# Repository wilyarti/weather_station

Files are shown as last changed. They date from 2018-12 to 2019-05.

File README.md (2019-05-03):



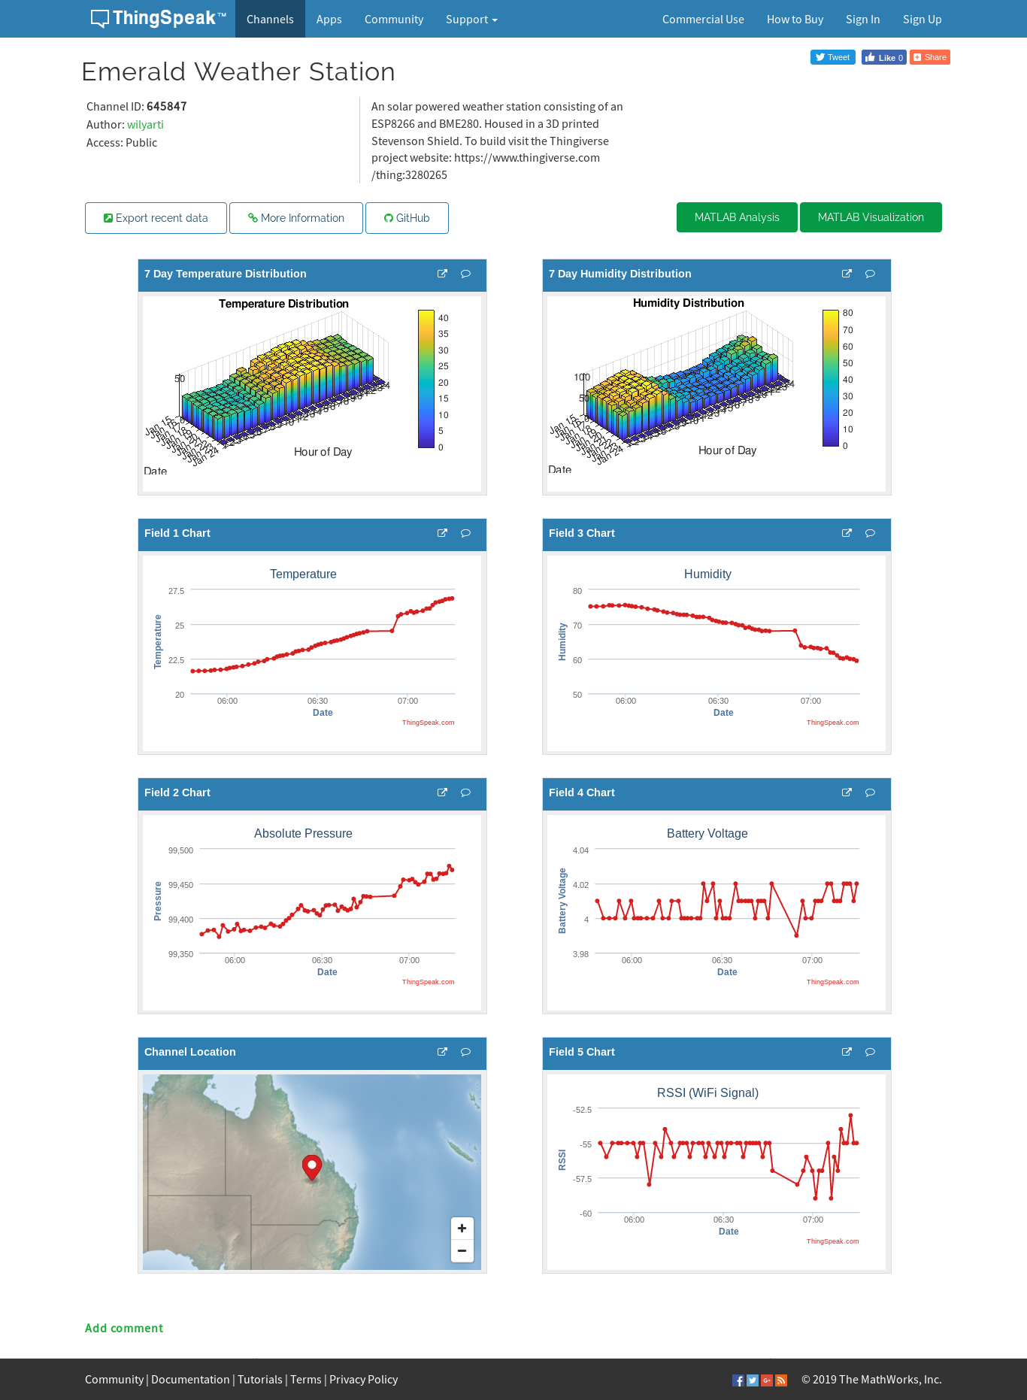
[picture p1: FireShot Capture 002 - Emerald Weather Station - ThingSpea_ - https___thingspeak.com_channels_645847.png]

# Introduction
This weather station has evolved over time. I originally undersized the roof and solar panels and created about 4 different versions. I started with a 0.1W solar panel (110mmx60mm) but it was under powered and only reached charge in the later afternoon.

My latest version uses a 165mm square solar panel and allows for the device to measure more frequently (every minute vs 5 minutes), I think it would be sufficient for low lit areas.

The latest firmware will create a WiFi access point that you can connect if the device is unable to connect to the internet via WiFi. This allows you to enter your ThingSpeak credentials, the sampling interval in seconds, and the WiFi access point credentials you would like to connect to. To access this page connect to the the ESP access point (named ESP... something) and navigate to http://192.168.4.1 and click on the relevent buttons.

After configuring the ESP's WiFi access point will disappear if it was configured correctly.

# Building
First select the roof based on the solar panel you are using and print all the parts. The parts are have all the holes necessary so all you need to do is screw it together.

# Configuring
Create a ThingSpeak account and a channel. Enter this channel number and your credentials into the ESP8266 configuration page that appears when you connect to the access point (as discussed above).

You can the code for a cool 3D bar graph in my GitHub repository, simple copy this and replace my ThingSpeak channel number with your own.

# Issues
Solar radiation is a big problem and will cause the inside of the structure to heat up. You will need to paint any surface that comes in contact with the sun with many layers of exterior UV resistant paint (I used high gloss and about 6 coats).

The latest design uses a large gap below the roof (which holds the solar panel) to allow for air flow. The roof is designed so that water will accumulate and drip off areas away from the electronics - although I am yet to prove it is sufficiently water resistant.

This version does not go to sleep, as it needs to listen for external interrupts to measure rain fall.

# Weather Issues and Web Interface
There were problems with previous version in wild weather where pressurized air would blow water into the internal Stevenson Screen damaging electronic components.

I have since devised a better design which seems to be more resistant to water ingress.

However it is not totally weather proof and strong winds and rain fall can still cause damages.

I have run out of ideas on how to solve this and any input is welcome.

You can use my web interface to view public ThingSpeak channels (see link below). It includes the following features:

1. Rain totals by 30 min, 1hr and 24 hr intervals
2. Live feed updates (1min)
3. Auto Absolute to Mean Sea Level Pressure conversion
4. Custom date ranges 
5. Custom interval ranges

# OTA Update
To configure Over The Air updates simple add this to your metadata field on your ThingSpeak channel:
~~~~
{
      "publishInterval" : 30,
      "firmwareVersion" : "11",
      "firmwareURL" : "link to firmware url"
}
~~~~
Don't forget to increment your firmware version in the source code as well (to prevent continuous upgrading to the same firmware):
~~~~
const String VERSION = "11";

~~~~

To generate the firmware "compilation" under "Show verbose output during: " in the Arduino settings dialog. Then copy the firmware listed in the compilation status window after clicking compile:
~~~~
<snip>
/home/undef/.arduino15/packages/esp8266/tools/xtensa-lx106-elf-gcc/1.20.0-26-gb404fb9-2/bin/xtensa-lx106-elf-size -A /tmp/arduino_build_27952/thingspeak_ota_weatherstation.ino.elf
Sketch uses 324156 bytes (31%) of program storage space. Maximum is 1044464 bytes.
Global variables use 32228 bytes (39%) of dynamic memory, leaving 49692 bytes for local variables. Maximum is 81920 bytes.

~~~~

In this case the firmware is located here: /tmp/arduino_build_27952/thingspeak_ota_weatherstation.ino.elf

# Parts list
- 18650 battery holder
- Diode for the solar panel
- Any ESP8266/ESP8285 module 
- TP4056 Battery Charger (or MCP73871 solar board)
- 6v Solar panel (165mmx165mm recommended)
- BME280 sensor
- SHT31 sensor
- UV VEML6075 Sensor
- Cabling
- Hot Glue
- Silicon Sealant (optional)
- Exterior UV resistant paint

[View source code.](https://github.com/wilyarti/weather_station "Source code.")
[View live data.](https://thingspeak.com/channels/645847 "View live data.")
[Use my API viewer.](https://opens3.net/weatherstats.html "Custom API Viewer")
[View Thingiverse entry](https://www.thingiverse.com/thing:3601839)

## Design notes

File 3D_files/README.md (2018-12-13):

### 3D files
These are the STL files, the project was created using AutoDesk Inventor. I will upload the ipt files at a later date.

The roof is foldable, in order to use it remove it from the build plate and allow to cool. Then place on the built plate and pre-heat the printer to 85c. When the part has heated fold and place up the right way and allow it to cool.

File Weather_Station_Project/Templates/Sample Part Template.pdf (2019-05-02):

THE INFORMATION AND/OR MATERIAL IN THIS DOCUMENT IS THE PROPERTY OF AND RESTRICTED INFORMATION AND/OR MATERIAL OF THE AUTHOR. THIS INFORMATION MAY NOT BE
USED, REPRODUCED, PUBLISHED OR DISCLOSED TO OTHERS WITHOUT WRITTEN AUTHORIZATION. IT IS TO BE USED ONLY FOR MANUFACTURING ITEMS SPECIFIED WITHIN THE DOCUMENT. {{{ 'v1.0' }}}

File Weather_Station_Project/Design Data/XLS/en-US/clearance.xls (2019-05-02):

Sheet: Ansi Unified Screw Threads
I | Sort Order -1
Fastener Type | Size | Shaft Diameters |  |  | Head Dimensions
 |  | Close | Normal | Loose | Diameter | Depth/Angle | Head Type
Flat Head Machine Screw (82) | #0 | 0.0635 | 0.07 | 0.073 | 0.119 | 82 | 2
Flat Head Machine Screw (82) | #1 | 0.076 | 0.081 | 0.089 | 0.146 | 82 | 2
Flat Head Machine Screw (82) | #2 | 0.089 | 0.096 | 0.1065 | 0.172 | 82 | 2
Flat Head Machine Screw (82) | #3 | 0.104 | 0.11 | 0.12 | 0.199 | 82 | 2
Flat Head Machine Screw (82) | #4 | 0.116 | 0.1285 | 0.136 | 0.225 | 82 | 2
Flat Head Machine Screw (82) | #5 | 0.1285 | 0.136 | 0.154 | 0.252 | 82 | 2
Flat Head Machine Screw (82) | #6 | 0.144 | 0.1495 | 0.1695 | 0.279 | 82 | 2
Flat Head Machine Screw (82) | #8 | 0.1695 | 0.177 | 0.1935 | 0.332 | 82 | 2
Flat Head Machine Screw (82) | #10 | 0.196 | 0.201 | 0.221 | 0.385 | 82 | 2
Flat Head Machine Screw (82) | #12 | 0.221 | 0.228 | 0.246 | 0.438 | 82 | 2
Flat Head Machine Screw (82) | 1/4 | 0.257 | 0.266 | 0.2812 | 0.507 | 82 | 2
Flat Head Machine Screw (82) | 5/16 | 0.323 | 0.332 | 0.3437 | 0.635 | 82 | 2
Flat Head Machine Screw (82) | 3/8 | 0.386 | 0.397 | 0.4062 | 0.762 | 82 | 2
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

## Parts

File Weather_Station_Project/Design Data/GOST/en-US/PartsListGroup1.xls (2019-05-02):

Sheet: Лист 1
Инв. № подл |  |  |  | Подп. и дата | Взам. инв. № | Инв. № дубл. |  |  | Подп. и дата
Формат | Зона | Поз. | Обозначение |  |  |  | Наименование |  |  |  |  |  | Кол. на исполнение
 |  |  |  |  |  |  |  |  |  |  |  | Лит.
 |  |  |  |  |  |  |  |  |  |  |  | Код
 |  |  |  |  |  |  |  | Изм. | Лист | № докум | Подпись |  | Дата
 |  |  |  |  |  |  |  | Разраб.
 |  |  |  |  |  |  |  | Пров.
 |  |  |  |  |  |  |  | Н.контр
 |  |  |  |  |  |  |  | Утв.
 |  |  |  |  |  |  |  |  |  |  |  |  |  | Копировал

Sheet: Лист 2
Инв. № подл |  |  |  | Подп. и дата | Взам. инв. № | Инв. № дубл. |  |  | Подп. и дата
Формат | Зона | Поз. | Обозначение |  |  |  | Наименование |  |  |  |  | Кол. на исполнение
 |  |  |  |  |  |  |  | Изм. | Лист | № докум. | Подп. | Дата
 |  |  |  |  |  |  |  |  |  |  |  |  | Копировал
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

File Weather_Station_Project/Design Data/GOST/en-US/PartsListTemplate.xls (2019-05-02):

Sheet: Лист 1
 | Формат | Зона |  | Поз. |  | Обозначение |  |  |  | Наименование |  |  |  | Кол. | Приме-чание
Подп. и дата
Инв. № дубл.
Взам. инв. №
Подп. и дата
 | Изм. |  | Лист |  | № докум |  | Подпись | Дата
Инв. № подл | Разраб. |  |  |  |  |  |  |  |  |  | Литера |  | Лист |  |  | Листов
 | Пров.
 | Н.контр
 | Утв.
 |  |  |  |  |  |  |  |  | Копировал |  |  | Формат А4

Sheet: Лист 2
 | Формат | Зона |  | Поз. |  | Обозначение |  |  |  | Наименование |  | Кол. | Приме-чание
Подп. и дата
Инв. № дубл.
Взам. инв. №
Подп. и дата
Инв. № подл
 | Изм. |  | Лист |  | № докум. |  | Подп. |  | Дата
 |  |  |  |  |  |  |  | Копировал |  |  | Формат А4
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

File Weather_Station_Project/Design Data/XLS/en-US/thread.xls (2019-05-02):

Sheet: Inch Tapping Threads
I Q X | Inch Tapping Threads |  | Sort Order - 5 |  | External |  |  |  |  |  |  | Internal
 |  |  |  |  |  | Major Dia |  | Pitch Dia |  | Minor Dia |  |  | Minor Dia |  | Pitch Dia |  | Major Dia |  | Tap Drill
Size | Size Suffix | Thread Designation | Custom Thread Designation | TPI | Class | Max | Min | Max | Min | Max | Min | Class | Min | Max | Min | Max | Min | Max | Basic
0.0600 |  | 0-48 | 0-48 | 48 | 2B | 0.0600 | 0.0540 | 0.0480 | 0.0435 | 0.0360 | 0.0330
0.0730 |  | 1-42 | 1-42 | 42 | 2B | 0.0750 | 0.0690 | 0.0620 | 0.0575 | 0.0490 | 0.0460
0.0860 |  | 2-32 | 2-32 | 32 | 2B | 0.0880 | 0.0820 | 0.0760 | 0.0710 | 0.0640 | 0.0600
0.0990 |  | 3-28 | 3-28 | 28 | 2B | 0.1010 | 0.0950 | 0.0880 | 0.0830 | 0.0750 | 0.0710
0.1120 |  | 4-24 | 4-24 | 24 | 2B | 0.1140 | 0.1080 | 0.1000 | 0.0950 | 0.0860 | 0.0820
0.1250 |  | 5-20 | 5-20 | 20 | 2B | 0.1300 | 0.1230 | 0.1120 | 0.1065 | 0.0940 | 0.0900
0.1380 |  | 6-20 | 6-20 | 20 | 2B | 0.1390 | 0.1320 | 0.1215 | 0.1155 | 0.1040 | 0.0990
0.1510 |  | 7-19 | 7-19 | 19 | 2B | 0.1540 | 0.1470 | 0.1345 | 0.1280 | 0.1150 | 0.1090
0.1640 |  | 8-18 | 8-18 | 18 | 2B | 0.1660 | 0.1590 | 0.1440 | 0.1375 | 0.1220 | 0.1160
0.1900 |  | 10-16 | 10-16 | 16 | 2B | 0.1890 | 0.1820 | 0.1650 | 0.1585 | 0.1410 | 0.1350
0.2160 |  | 12-14 | 12-14 | 14 | 2B | 0.2150 | 0.2080 | 0.1895 | 0.1825 | 0.1640 | 0.1570
0.2420 |  | 14-14 | 14-14 | 14 | 2B | 0.2410 | 0.2340 | 0.2130 | 0.2060 | 0.1850 | 0.1780
0.2500 |  | 1/4-14 | 1/4-14 | 14 | 2B | 0.2460 | 0.2370 | 0.2190 | 0.2110 | 0.1920 | 0.1850
0.3125 |  | 5/16-12 | 5/16-12 | 12 | 2B | 0.3150 | 0.3060 | 0.2795 | 0.2710 | 0.2440 | 0.2360
0.3750 |  | 3/8-12 | 3/8-12 | 12 | 2B | 0.3800 | 0.3710 | 0.3445 | 0.3350 | 0.3090 | 0.2990
0.4375 |  | 7/16-10 | 7/16-10 | 10 | 2B | 0.4400 | 0.4290 | 0.3995 | 0.3890 | 0.3590 | 0.3490
0.5000 |  | 1/2-10 | 1/2-10 | 10 | 2B | 0.5040 | 0.4930 | 0.4635 | 0.4530 | 0.4230 | 0.4130

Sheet: Metric Forming Screw Threads
M P X | Metric Forming Screw Threads |  | Sort Order - 6 |  | External |  |  |  |  |  |  | Internal
 |  |  |  |  |  | Major Dia |  | Pitch Dia |  | Minor Dia |  |  | Minor Dia |  | Pitch Dia |  | Major Dia |  | Tap Drill
Size | Size Suffix | Thread Designation | Custom Thread Designation | Pitch | Class | Max | Min | Max | Min | Max | Min | Class | Min | Max | Min | Max | Min | Max | Basic
1.5 |  | 1.5x0.5 | 1.5x0.5 | 0.5 | 6g | 1.520 | 1.380 | 1.215 | 1.110 | 0.910 | 0.840
1.5 |  | ST1.5x0.5 | ST1.5x0.5 | 0.5 | 6g | 1.520 | 1.380 | 1.215 | 1.110 | 0.910 | 0.840
1.9 |  | 1.9x0.6 | 1.9x0.6 | 0.6 | 6g | 1.900 | 1.760 | 1.570 | 1.465 | 1.240 | 1.170
1.9 |  | ST1.9x0.6 | ST1.9x0.6 | 0.6 | 6g | 1.900 | 1.760 | 1.570 | 1.465 | 1.240 | 1.170
2.2 |  | 2.2x0.8 | 2.2x0.8 | 0.8 | 6g | 2.240 | 2.100 | 1.935 | 1.810 | 1.630 | 1.520
2.2 |  | ST2.2x0.8 | ST2.2x0.8 | 0.8 | 6g | 2.240 | 2.100 | 1.935 | 1.810 | 1.630 | 1.520
2.6 |  | 2.6x0.9 | 2.6x0.9 | 0.9 | 6g | 2.570 | 2.430 | 2.235 | 2.115 | 1.900 | 1.800
2.6 |  | ST2.6x0.9 | ST2.6x0.9 | 0.9 | 6g | 2.570 | 2.430 | 2.235 | 2.115 | 1.900 | 1.800
2.9 |  | 2.9x1 | 2.9x1 | 1 | 6g | 2.900 | 2.760 | 2.540 | 2.420 | 2.180 | 2.080
2.9 |  | 2.9x1.1 | 2.9x1.1 | 1.1 | 6g | 2.900 | 2.760 | 2.540 | 2.420 | 2.180 | 2.080
2.9 |  | ST2.9x1.1 | ST2.9x1.1 | 1.1 | 6g | 2.900 | 2.760 | 2.540 | 2.420 | 2.180 | 2.080
2.9 |  | 2.9x1.3 | 2.9x1.3 | 1.3 | 6g | 2.900 | 2.720 | 2.540 | 2.355 | 1.890 | 1.700
2.9 |  | 2.9x1.4 | 2.9x1.4 | 1.4 | 6g | 2.900 | 2.720 | 2.340 | 2.175 | 1.780 | 1.630
3.3 |  | 3.3x1.3 | 3.3x1.3 | 1.3 | 6g | 3.300 | 3.120 | 2.795 | 2.665 | 2.290 | 2.210
3.3 |  | ST3.3x1.3 | ST3.3x1.3 | 1.3 | 6g | 3.300 | 3.120 | 2.795 | 2.665 | 2.290 | 2.210
3.5 |  | 3.5x1.3 | 3.5x1.3 | 1.3 | 6g | 3.530 | 3.350 | 3.085 | 2.930 | 2.640 | 2.510
3.5 |  | ST3.5x1.3 | ST3.5x1.3 | 1.3 | 6g | 3.530 | 3.350 | 3.085 | 2.930 | 2.640 | 2.510
3.5 |  | 3.5x1.6 | 3.5x1.6 | 1.6 | 6g | 3.530 | 3.350 | 2.920 | 2.755 | 2.310 | 2.160
3.5 |  | 3.5x3.2 | 3.5x3.2 | 3.2 | 6g | 3.530 | 3.310 | 2.800 | 2.600 | 2.070 | 1.890
3.9 |  | 3.9x1.3 | 3.9x1.3 | 1.3 | 6g | 3.910 | 3.730 | 3.415 | 3.250 | 2.920 | 2.770
3.9 |  | ST3.9x1.3 | ST3.9x1.3 | 1.3 | 6g | 3.910 | 3.730 | 3.415 | 3.250 | 2.920 | 2.770
3.9 |  | 3.9x1.6 | 3.9x1.6 | 1.6 | 6g | 3.910 | 3.730 | 3.300 | 3.135 | 2.690 | 2.540
3.9 |  | 3.9x3.2 | 3.9x3.2 | 3.2 | 6g | 3.910 | 3.690 | 3.180 | 2.980 | 2.450 | 2.270
4.2 |  | 4.2x1.4 | 4.2x1.4 | 1.4 | 6g | 4.220 | 4.040 | 3.660 | 3.495 | 3.100 | 2.950
4.2 |  | ST4.2x1.4 | ST4.2x1.4 | 1.4 | 6g | 4.220 | 4.040 | 3.660 | 3.495 | 3.100 | 2.950
4.2 |  | 4.2x1.6 | 4.2x1.6 | 1.6 | 6g | 4.220 | 4.040 | 3.610 | 3.445 | 3.000 | 2.850
4.2 |  | 4.2x3.2 | 4.2x3.2 | 3.2 | 6g | 4.220 | 4.000 | 3.380 | 3.180 | 2.540 | 2.360
4.8 |  | 4.8x1.6 | 4.8x1.6 | 1.6 | 6g | 4.800 | 4.620 | 4.190 | 4.025 | 3.580 | 3.430
4.8 |  | ST4.8x1.6 | ST4.8x1.6 | 1.6 | 6g | 4.800 | 4.620 | 4.190 | 4.025 | 3.580 | 3.430
4.8 |  | 4.8x1.8 | 4.8x1.8 | 1.8 | 6g | 4.800 | 4.620 | 4.065 | 3.885 | 3.330 | 3.150
4.8 |  | 4.8x3.2 | 4.8x3.2 | 3.2 | 6g | 4.800 | 4.580 | 3.960 | 3.760 | 3.120 | 2.940
5.5 |  | 5.5x1.8 | 5.5x1.8 | 1.8 | 6g | 5.460 | 5.280 | 4.815 | 4.635 | 4.170 | 3.990
5.5 |  | ST5.5x1.8 | ST5.5x1.8 | 1.8 | 6g | 5.460 | 5.280 | 4.815 | 4.635 | 4.170 | 3.990
6.3 |  | 6.3x1.8 | 6.3x1.8 | 1.8 | 6g | 6.250 | 6.030 | 5.565 | 5.365 | 4.880 | 4.700
6.3 |  | ST6.3x1.8 | ST6.3x1.8 | 1.8 | 6g | 6.250 | 6.030 | 5.565 | 5.365 | 4.880 | 4.700
8.0 |  | 8x2.1 | 8x2.1 | 2.1 | 6g | 8.000 | 7.780 | 7.100 | 6.885 | 6.200 | 5.990
8.0 |  | ST8x2.1 | ST8x2.1 | 2.1 | 6g | 8.000 | 7.780 | 7.100 | 6.885 | 6.200 | 5.990
9.5 |  | 9.5x2.1 | 9.5x2.1 | 2.1 | 6g | 9.650 | 9.430 | 8.750 | 8.510 | 7.850 | 7.590
9.5 |  | ST9.5x2.1 | ST9.5x2.1 | 2.1 | 6g | 9.650 | 9.430 | 8.750 | 8.510 | 7.850 | 7.590

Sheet: ISO Pipe Threads
M Q | ISO Pipe Threads |  | Sort Order - 9 |  | External |  |  |  |  |  |  | Internal
 |  |  |  |  |  | Major Dia |  | Pitch Dia |  | Minor Dia |  |  | Minor Dia |  | Pitch Dia |  | Major Dia |  | Tap Drill | Thread Depth | Thread Runouts
Size | Size Suffix | Thread Designation | Custom Thread Designation | TPI | Class | Max | Min | Max | Min | Max | Min | Class | Min | Max | Min | Max | Min | Max | Basic
7.723 |  | G7.723x0.907 | G 1/16 | 28 | A | 7.723 | 7.509 | 7.142 | 7.035 | 6.561 |  |  | 6.561 | 6.834 | 7.142 | 7.249 | 7.723 |  | 1.5875 | 15.446 | 4.5000
7.723 |  | G7.723x0.907 | G 1/16 | 28 | B | 7.723 | 7.509 | 7.142 | 6.928 | 6.561
9.728 |  | G9.728x0.907 | G 1/8 | 28 | A | 9.728 | 9.514 | 9.147 | 9.040 | 8.566 |  |  | 8.566 | 8.848 | 9.147 | 9.254 | 9.728 |  | 3.1750 | 19.456 | 4.5000
9.728 |  | G9.728x0.907 | G 1/8 | 28 | B | 9.728 | 9.514 | 9.147 | 8.933 | 8.566
13.157 |  | G13.157x1.337 | G 1/4 | 19 | A | 13.157 | 12.907 | 12.301 | 12.176 | 11.445 |  |  | 11.445 | 11.89 | 12.301 | 12.426 | 13.157 |  | 6.3500 | 26.314 | 6.5000
13.157 |  | G13.157x1.337 | G 1/4 | 19 | B | 13.157 | 12.907 | 12.301 | 12.051 | 11.445
16.662 |  | G16.662x1.337 | G 3/8 | 19 | A | 16.662 | 16.412 | 15.806 | 15.681 | 14.950 |  |  | 14.95 | 15.395 | 15.806 | 15.931 | 16.662 |  | 9.5250 | 33.324 | 6.5000
16.662 |  | G16.662x1.337 | G 3/8 | 19 | B | 16.662 | 16.412 | 15.806 | 15.556 | 14.950
20.955 |  | G20.955x1.814 | G 1/2 | 14 | A | 20.955 | 20.671 | 19.793 | 19.651 | 18.631 |  |  | 18.631 | 19.172 | 19.793 | 19.935 | 20.955 |  | 12.7000 | 41.910 | 8.5000
20.955 |  | G20.955x1.814 | G 1/2 | 14 | B | 20.955 | 20.671 | 19.793 | 19.509 | 18.631
22.911 |  | G22.911x1.814 | G 5/8 | 14 | A | 22.911 | 22.627 | 21.749 | 21.607 | 20.587 |  |  | 20.587 | 21.128 | 21.749 | 21.891 | 22.911 |  |  | 45.822 | 8.5000
22.911 |  | G22.911x1.814 | G 5/8 | 14 | B | 22.911 | 22.627 | 21.749 | 21.465 | 20.587
26.441 |  | G26.441x1.814 | G 3/4 | 14 | A | 26.441 | 26.157 | 25.279 | 25.137 | 24.117 |  |  | 24.117 | 24.658 | 25.279 | 25.421 | 26.441 |  | 15.8750 | 52.882 | 8.5000
26.441 |  | G26.441x1.814 | G 3/4 | 14 | B | 26.441 | 26.157 | 25.279 | 24.995 | 24.117
30.201 |  | G30.201x1.814 | G 7/8 | 14 | A | 30.201 | 29.917 | 29.039 | 28.897 | 27.877 |  |  | 27.877 | 28.418 | 29.039 | 29.181 | 30.201 |  | 22.2250 | 60.402 | 8.5000
30.201 |  | G30.201x1.814 | G 7/8 | 14 | B | 30.201 | 29.917 | 29.039 | 28.755 | 27.877
33.249 |  | G33.249x2.309 | G 1 | 11 | A | 33.249 | 32.889 | 31.770 | 31.590 | 30.291 |  |  | 30.291 | 30.931 | 31.77 | 31.95 | 33.249 |  | 25.4000 | 66.498 | 10.0000
33.249 |  | G33.249x2.309 | G 1 | 11 | B | 33.249 | 32.889 | 31.770 | 31.410 | 30.291
37.897 |  | G37.897x2.309 | G 1 1/8 | 11 | A | 37.897 | 37.537 | 36.418 | 36.238 | 34.939 |  |  | 34.939 | 35.579 | 36.418 | 36.598 | 37.897 |  | 28.5750 | 75.794 | 10.0000
37.897 |  | G37.897x2.309 | G 1 1/8 | 11 | B | 37.897 | 37.537 | 36.418 | 36.058 | 34.939
41.910 |  | G41.91x2.309 | G 1 1/4 | 11 | A | 41.910 | 41.550 | 40.431 | 40.251 | 38.952 |  |  | 38.952 | 39.592 | 40.431 | 40.611 | 41.910 |  | 31.7500 | 83.820 | 10.0000
41.910 |  | G41.91x2.309 | G 1 1/4 | 11 | B | 41.910 | 41.550 | 40.431 | 40.071 | 38.952
47.803 |  | G47.803x2.309 | G 1 1/2 | 11 | A | 47.803 | 47.443 | 46.324 | 46.144 | 44.845 |  |  | 44.845 | 45.485 | 46.324 | 46.504 | 47.803 |  | 38.1000 | 95.606 | 10.0000
47.803 |  | G47.803x2.309 | G 1 1/2 | 11 | B | 47.803 | 47.443 | 46.324 | 45.964 | 44.845
53.746 |  | G53.746x2.309 | G 1 3/4 | 11 | A | 53.746 | 53.386 | 52.267 | 52.087 | 50.788 |  |  | 50.788 | 51.428 | 52.267 | 52.447 | 53.746 |  | 44.4500 | 107.492 | 10.0000
53.746 |  | G53.746x2.309 | G 1 3/4 | 11 | B | 53.746 | 53.386 | 52.267 | 51.907 | 50.788
59.614 |  | G59.614x2.309 | G 2 | 11 | A | 59.614 | 59.254 | 58.135 | 57.955 | 56.656 |  |  | 56.656 | 57.296 | 58.135 | 58.315 | 59.614 |  | 50.8000 | 119.228 | 10.0000
59.614 |  | G59.614x2.309 | G 2 | 11 | B | 59.614 | 59.254 | 58.135 | 57.775 | 56.656
65.710 |  | G65.71x2.309 | G 2 1/4 | 11 | A | 65.710 | 65.276 | 64.231 | 64.014 | 62.752 |  |  | 62.752 | 63.392 | 64.231 | 64.448 | 65.710 |  | 57.1500 | 131.420 | 10.0000
65.710 |  | G65.71x2.309 | G 2 1/4 | 11 | B | 65.710 | 65.276 | 64.231 | 63.797 | 62.752
75.184 |  | G75.184x2.309 | G 2 1/2 | 11 | A | 75.184 | 74.750 | 73.705 | 73.488 | 72.226 |  |  | 72.226 | 72.866 | 73.705 | 73.922 | 75.184 |  |  | 150.368 | 10.0000
75.184 |  | G75.184x2.309 | G 2 1/2 | 11 | B | 75.184 | 74.750 | 73.705 | 73.271 | 72.226
81.534 |  | G81.534x2.309 | G 2 3/4 | 11 | A | 81.534 | 81.100 | 80.055 | 79.838 | 78.576 |  |  | 78.576 | 79.216 | 80.055 | 80.272 | 81.534 |  | 69.8500 | 163.068 | 10.0000
81.534 |  | G81.534x2.309 | G 2 3/4 | 11 | B | 81.534 | 81.100 | 80.055 | 79.621 | 78.576
87.884 |  | G87.884x2.309 | G 3 | 11 | A | 87.884 | 87.450 | 86.405 | 86.188 | 84.926 |  |  | 84.926 | 85.566 | 86.405 | 86.622 | 87.884 |  | 76.2000 | 175.768 | 10.0000
87.884 |  | G87.884x2.309 | G 3 | 11 | B | 87.884 | 87.450 | 86.405 | 85.971 | 84.926
100.330 |  | G100.33x2.309 | G 3 1/2 | 11 | A | 100.330 | 99.896 | 98.851 | 98.634 | 97.372 |  |  | 97.372 | 98.012 | 98.851 | 99.068 | 100.330 |  | 88.9000 | 200.660 | 10.0000
100.330 |  | G100.33x2.309 | G 3 1/2 | 11 | B | 100.330 | 99.896 | 98.851 | 98.417 | 97.372
113.030 |  | G113.03x2.309 | G 4 | 11 | A | 113.030 | 112.596 | 111.551 | 111.334 | 110.072 |  |  | 110.072 | 110.712 | 111.551 | 111.768 | 113.030 |  | 101.6000 | 226.060 | 10.0000
113.030 |  | G113.03x2.309 | G 4 | 11 | B | 113.030 | 112.596 | 111.551 | 111.117 | 110.072
125.730 |  | G125.73x2.309 | G 4 1/2 | 11 | A | 125.730 | 125.296 | 124.251 | 124.034 | 122.772 |  |  | 122.772 | 123.412 | 124.251 | 124.468 | 125.730 |  | 114.3000 | 251.460 | 10.0000
125.730 |  | G125.73x2.309 | G 4 1/2 | 11 | B | 125.730 | 125.296 | 124.251 | 123.817 | 122.772
138.430 |  | G138.43x2.309 | G 5 | 11 | A | 138.430 | 137.996 | 136.951 | 136.734 | 135.472 |  |  | 135.472 | 136.112 | 136.951 | 137.168 | 138.430 |  | 127.0000 | 276.860 | 10.0000
138.430 |  | G138.43x2.309 | G 5 | 11 | B | 138.430 | 137.996 | 136.951 | 136.517 | 135.472
151.130 |  | G151.13x2.309 | G 5 1/2 | 11 | A | 151.130 | 150.696 | 149.651 | 149.434 | 148.172 |  |  | 148.172 | 148.812 | 149.651 | 149.868 | 151.130 |  | 139.7000 | 302.260 | 10.0000
151.130 |  | G151.13x2.309 | G 5 1/2 | 11 | B | 151.130 | 150.696 | 149.651 | 149.217 | 148.172
163.830 |  | G163.83x2.309 | G 6 | 11 | A | 163.830 | 163.396 | 162.351 | 162.134 | 160.872 |  |  | 160.872 | 161.512 | 162.351 | 162.568 | 163.830 |  | 152.4000 | 327.660 | 10.0000
163.830 |  | G163.83x2.309 | G 6 | 11 | B | 163.830 | 163.396 | 162.351 | 161.917 | 160.872

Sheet: JIS Pipe Threads
M Q | JIS Pipe Threads |  | Sort Order -12 |  | External |  |  |  |  |  |  | Internal
 |  |  |  |  |  | Major Dia |  | Pitch Dia |  | Minor Dia |  |  | Minor Dia |  | Pitch Dia |  | Major Dia |  | Tap Drill | Thread Depth | Thread Runouts
Size | Size Suffix | Thread Designation | Custom Thread Designation | TPI | Class | Max | Min | Max | Min | Max | Min | Class | Min | Max | Min | Max | Min | Max | Basic |  | Basic
7.723 |  | G7.723x0.907 | G 1/16 | 28 | A | 7.723 | 7.509 | 7.142 | 7.035 | 6.561 |  |  | 6.561 | 6.834 | 7.142 | 7.249 | 7.723 |  | 1.5875 | 15.446 | 4.5000
7.723 |  | G7.723x0.907 | G 1/16 | 28 | B | 7.723 | 7.509 | 7.142 | 6.928 | 6.561
9.728 |  | G9.728x0.907 | G 1/8 | 28 | A | 9.728 | 9.514 | 9.147 | 9.040 | 8.566 |  |  | 8.566 | 8.848 | 9.147 | 9.254 | 9.728 |  | 3.1750 | 19.456 | 4.5000
9.728 |  | G9.728x0.907 | G 1/8 | 28 | B | 9.728 | 9.514 | 9.147 | 8.933 | 8.566
13.157 |  | G13.157x1.337 | G 1/4 | 19 | A | 13.157 | 12.907 | 12.301 | 12.176 | 11.445 |  |  | 11.445 | 11.89 | 12.301 | 12.426 | 13.157 |  | 6.3500 | 26.314 | 6.5000
13.157 |  | G13.157x1.337 | G 1/4 | 19 | B | 13.157 | 12.907 | 12.301 | 12.051 | 11.445
16.662 |  | G16.662x1.337 | G 3/8 | 19 | A | 16.662 | 16.412 | 15.806 | 15.681 | 14.950 |  |  | 14.95 | 15.395 | 15.806 | 15.931 | 16.662 |  | 9.5250 | 33.324 | 6.5000
16.662 |  | G16.662x1.337 | G 3/8 | 19 | B | 16.662 | 16.412 | 15.806 | 15.556 | 14.950
20.955 |  | G20.955x1.814 | G 1/2 | 14 | A | 20.955 | 20.671 | 19.793 | 19.651 | 18.631 |  |  | 18.631 | 19.172 | 19.793 | 19.935 | 20.955 |  | 12.7000 | 41.910 | 8.5000
20.955 |  | G20.955x1.814 | G 1/2 | 14 | B | 20.955 | 20.671 | 19.793 | 19.509 | 18.631
22.911 |  | G22.911x1.814 | G 5/8 | 14 | A | 22.911 | 22.627 | 21.749 | 21.607 | 20.587 |  |  | 20.587 | 21.128 | 21.749 | 21.891 | 22.911 |  |  | 45.822 | 8.5000
22.911 |  | G22.911x1.814 | G 5/8 | 14 | B | 22.911 | 22.627 | 21.749 | 21.465 | 20.587
26.441 |  | G26.441x1.814 | G 3/4 | 14 | A | 26.441 | 26.157 | 25.279 | 25.137 | 24.117 |  |  | 24.117 | 24.658 | 25.279 | 25.421 | 26.441 |  | 15.8750 | 52.882 | 8.5000
26.441 |  | G26.441x1.814 | G 3/4 | 14 | B | 26.441 | 26.157 | 25.279 | 24.995 | 24.117
30.201 |  | G30.201x1.814 | G 7/8 | 14 | A | 30.201 | 29.917 | 29.039 | 28.897 | 27.877 |  |  | 27.877 | 28.418 | 29.039 | 29.181 | 30.201 |  | 22.2250 | 60.402 | 8.8000
30.201 |  | G30.201x1.814 | G 7/8 | 14 | B | 30.201 | 29.917 | 29.039 | 28.755 | 27.877
33.249 |  | G33.249x2.309 | G 1 | 11 | A | 33.249 | 32.889 | 31.770 | 31.590 | 30.291 |  |  | 30.291 | 30.931 | 31.77 | 31.95 | 33.249 |  | 25.4000 | 66.498 | 10.0000
33.249 |  | G33.249x2.309 | G 1 | 11 | B | 33.249 | 32.889 | 31.770 | 31.410 | 30.291
37.897 |  | G37.897x2.309 | G 1 1/8 | 11 | A | 37.897 | 37.537 | 36.418 | 36.238 | 34.939 |  |  | 34.939 | 35.579 | 36.418 | 36.598 | 37.897 |  | 28.5750 | 75.794 | 10.0000
37.897 |  | G37.897x2.309 | G 1 1/8 | 11 | B | 37.897 | 37.537 | 36.418 | 36.058 | 34.939
41.910 |  | G41.91x2.309 | G 1 1/4 | 11 | A | 41.910 | 41.550 | 40.431 | 40.251 | 38.952 |  |  | 38.952 | 39.592 | 40.431 | 40.611 | 41.910 |  | 31.7500 | 83.820 | 10.0000
41.910 |  | G41.91x2.309 | G 1 1/4 | 11 | B | 41.910 | 41.550 | 40.431 | 40.071 | 38.952
47.803 |  | G47.803x2.309 | G 1 1/2 | 11 | A | 47.803 | 47.443 | 46.324 | 46.144 | 44.845 |  |  | 44.845 | 45.485 | 46.324 | 46.504 | 47.803 |  | 38.1000 | 95.606 | 10.0000
47.803 |  | G47.803x2.309 | G 1 1/2 | 11 | B | 47.803 | 47.443 | 46.324 | 45.964 | 44.845
53.746 |  | G53.746x2.309 | G 1 3/4 | 11 | A | 53.746 | 53.386 | 52.267 | 52.087 | 50.788 |  |  | 50.788 | 51.428 | 52.267 | 52.447 | 53.746 |  | 44.4500 | 107.492 | 10.0000
53.746 |  | G53.746x2.309 | G 1 3/4 | 11 | B | 53.746 | 53.386 | 52.267 | 51.907 | 50.788
59.614 |  | G59.614x2.309 | G 2 | 11 | A | 59.614 | 59.254 | 58.135 | 57.955 | 56.656 |  |  | 56.656 | 57.296 | 58.135 | 58.315 | 59.614 |  | 50.8000 | 119.228 | 10.0000
59.614 |  | G59.614x2.309 | G 2 | 11 | B | 59.614 | 59.254 | 58.135 | 57.775 | 56.656
65.710 |  | G65.71x2.309 | G 2 1/4 | 11 | A | 65.710 | 65.276 | 64.231 | 64.014 | 62.752 |  |  | 62.752 | 63.392 | 64.231 | 64.448 | 65.710 |  | 57.1500 | 131.420 | 10.0000
65.710 |  | G65.71x2.309 | G 2 1/4 | 11 | B | 65.710 | 65.276 | 64.231 | 63.797 | 62.752
75.184 |  | G75.184x2.309 | G 2 1/2 | 11 | A | 75.184 | 74.750 | 73.705 | 73.488 | 72.226 |  |  | 72.226 | 72.866 | 73.705 | 73.922 | 75.184 |  |  | 150.368 | 10.0000
75.184 |  | G75.184x2.309 | G 2 1/2 | 11 | B | 75.184 | 74.750 | 73.705 | 73.271 | 72.226
81.534 |  | G81.534x2.309 | G 2 3/4 | 11 | A | 81.534 | 81.100 | 80.055 | 79.838 | 78.576 |  |  | 78.576 | 79.216 | 80.055 | 80.272 | 81.534 |  | 69.8500 | 163.068 | 10.0000
81.534 |  | G81.534x2.309 | G 2 3/4 | 11 | B | 81.534 | 81.100 | 80.055 | 79.621 | 78.576
87.884 |  | G87.884x2.309 | G 3 | 11 | A | 87.884 | 87.450 | 86.405 | 86.188 | 84.926 |  |  | 84.926 | 85.566 | 86.405 | 86.622 | 87.884 |  | 76.2000 | 175.768 | 10.0000
87.884 |  | G87.884x2.309 | G 3 | 11 | B | 87.884 | 87.450 | 86.405 | 85.971 | 84.926
100.330 |  | G100.33x2.309 | G 3 1/2 | 11 | A | 100.330 | 99.896 | 98.851 | 98.634 | 97.372 |  |  | 97.372 | 98.012 | 98.851 | 99.068 | 100.330 |  | 88.9000 | 200.660 | 10.0000
100.330 |  | G100.33x2.309 | G 3 1/2 | 11 | B | 100.330 | 99.896 | 98.851 | 98.417 | 97.372
113.030 |  | G113.03x2.309 | G 4 | 11 | A | 113.030 | 112.596 | 111.551 | 111.334 | 110.072 |  |  | 110.072 | 110.712 | 111.551 | 111.768 | 113.030 |  | 101.6000 | 226.060 | 10.0000
113.030 |  | G113.03x2.309 | G 4 | 11 | B | 113.030 | 112.596 | 111.551 | 111.117 | 110.072
125.730 |  | G125.73x2.309 | G 4 1/2 | 11 | A | 125.730 | 125.296 | 124.251 | 124.034 | 122.772 |  |  | 122.772 | 123.412 | 124.251 | 124.468 | 125.730 |  | 114.3000 | 251.460 | 10.0000
125.730 |  | G125.73x2.309 | G 4 1/2 | 11 | B | 125.730 | 125.296 | 124.251 | 123.817 | 122.772
138.430 |  | G138.43x2.309 | G 5 | 11 | A | 138.430 | 137.996 | 136.951 | 136.734 | 135.472 |  |  | 135.472 | 136.112 | 136.951 | 137.168 | 138.430 |  | 127.0000 | 276.860 | 10.0000
138.430 |  | G138.43x2.309 | G 5 | 11 | B | 138.430 | 137.996 | 136.951 | 136.517 | 135.472
151.130 |  | G151.13x2.309 | G 5 1/2 | 11 | A | 151.130 | 150.696 | 149.651 | 149.434 | 148.172 |  |  | 148.172 | 148.812 | 149.651 | 149.868 | 151.130 |  | 139.7000 | 302.260 | 10.0000
151.130 |  | G151.13x2.309 | G 5 1/2 | 11 | B | 151.130 | 150.696 | 149.651 | 149.217 | 148.172
163.830 |  | G163.83x2.309 | G 6 | 11 | A | 163.830 | 163.396 | 162.351 | 162.134 | 160.872 |  |  | 160.872 | 161.512 | 162.351 | 162.568 | 163.830 |  | 152.4000 | 327.660 | 10.0000
163.830 |  | G163.83x2.309 | G 6 | 11 | B | 163.830 | 163.396 | 162.351 | 161.917 | 160.872

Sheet: DIN Pipe Threads
M Q | DIN Pipe Threads |  | Sort Order - 18 |  | External |  |  |  |  |  |  | Internal
 |  |  |  |  |  | Major Dia |  | Pitch Dia |  | Minor Dia |  |  | Minor Dia |  | Pitch Dia |  | Major Dia |  | Tap Drill | Thread Depth | Thread Runouts
Size | Size Suffix | Thread Designation | Custom Thread Designation | TPI | Class | Max | Min | Max | Min | Max | Min | Class | Min | Max | Min | Max | Min | Max | Basic
7.723 |  | G7.723x0.907 | G 1/16 | 28 | A | 7.723 | 7.509 | 7.142 | 7.035 | 6.561 |  |  | 6.561 | 6.834 | 7.142 | 7.249 | 7.723 |  | 1.5875 | 15.446 | 4.5000
7.723 |  | G7.723x0.907 | G 1/16 | 28 | B | 7.723 | 7.509 | 7.142 | 6.928 | 6.561
9.728 |  | G9.728x0.907 | G 1/8 | 28 | A | 9.728 | 9.514 | 9.147 | 9.040 | 8.566 |  |  | 8.566 | 8.848 | 9.147 | 9.254 | 9.728 |  | 3.1750 | 19.456 | 4.5000
9.728 |  | G9.728x0.907 | G 1/8 | 28 | B | 9.728 | 9.514 | 9.147 | 8.933 | 8.566
13.157 |  | G13.157x1.337 | G 1/4 | 19 | A | 13.157 | 12.907 | 12.301 | 12.176 | 11.445 |  |  | 11.445 | 11.89 | 12.301 | 12.426 | 13.157 |  | 6.3500 | 26.314 | 6.5000
13.157 |  | G13.157x1.337 | G 1/4 | 19 | B | 13.157 | 12.907 | 12.301 | 12.051 | 11.445
16.662 |  | G16.662x1.337 | G 3/8 | 19 | A | 16.662 | 16.412 | 15.806 | 15.681 | 14.950 |  |  | 14.95 | 15.395 | 15.806 | 15.931 | 16.662 |  | 9.5250 | 33.324 | 6.5000
16.662 |  | G16.662x1.337 | G 3/8 | 19 | B | 16.662 | 16.412 | 15.806 | 15.556 | 14.950
20.955 |  | G20.955x1.814 | G 1/2 | 14 | A | 20.955 | 20.671 | 19.793 | 19.651 | 18.631 |  |  | 18.631 | 19.172 | 19.793 | 19.935 | 20.955 |  | 12.7000 | 41.910 | 8.5000
20.955 |  | G20.955x1.814 | G 1/2 | 14 | B | 20.955 | 20.671 | 19.793 | 19.509 | 18.631
22.911 |  | G22.911x1.814 | G 5/8 | 14 | A | 22.911 | 22.627 | 21.749 | 21.607 | 20.587 |  |  | 20.587 | 21.128 | 21.749 | 21.891 | 22.911 |  |  | 45.822 | 8.5000
22.911 |  | G22.911x1.814 | G 5/8 | 14 | B | 22.911 | 22.627 | 21.749 | 21.465 | 20.587
26.441 |  | G26.441x1.814 | G 3/4 | 14 | A | 26.441 | 26.157 | 25.279 | 25.137 | 24.117 |  |  | 24.117 | 24.658 | 25.279 | 25.421 | 26.441 |  | 15.8750 | 52.882 | 8.5000
26.441 |  | G26.441x1.814 | G 3/4 | 14 | B | 26.441 | 26.157 | 25.279 | 24.995 | 24.117
30.201 |  | G30.201x1.814 | G 7/8 | 14 | A | 30.201 | 29.917 | 29.039 | 28.897 | 27.877 |  |  | 27.877 | 28.418 | 29.039 | 29.181 | 30.201 |  | 22.2250 | 60.402 | 8.5000
30.201 |  | G30.201x1.814 | G 7/8 | 14 | B | 30.201 | 29.917 | 29.039 | 28.755 | 27.877
33.249 |  | G33.249x2.309 | G 1 | 11 | A | 33.249 | 32.889 | 31.770 | 31.590 | 30.291 |  |  | 30.291 | 30.931 | 31.77 | 31.95 | 33.249 |  | 25.4000 | 66.498 | 10.5000
33.249 |  | G33.249x2.309 | G 1 | 11 | B | 33.249 | 32.889 | 31.770 | 31.410 | 30.291
37.897 |  | G37.897x2.309 | G 1 1/8 | 11 | A | 37.897 | 37.537 | 36.418 | 36.238 | 34.939 |  |  | 34.939 | 35.579 | 36.418 | 36.598 | 37.897 |  | 28.5750 | 75.794 | 10.5000
37.897 |  | G37.897x2.309 | G 1 1/8 | 11 | B | 37.897 | 37.537 | 36.418 | 36.058 | 34.939
41.910 |  | G41.91x2.309 | G 1 1/4 | 11 | A | 41.910 | 41.550 | 40.431 | 40.251 | 38.952 |  |  | 38.952 | 39.592 | 40.431 | 40.611 | 41.910 |  | 31.7500 | 83.820 | 10.5000
41.910 |  | G41.91x2.309 | G 1 1/4 | 11 | B | 41.910 | 41.550 | 40.431 | 40.071 | 38.952
47.803 |  | G47.803x2.309 | G 1 1/2 | 11 | A | 47.803 | 47.443 | 46.324 | 46.144 | 44.845 |  |  | 44.845 | 45.485 | 46.324 | 46.504 | 47.803 |  | 38.1000 | 95.606 | 10.5000
47.803 |  | G47.803x2.309 | G 1 1/2 | 11 | B | 47.803 | 47.443 | 46.324 | 45.964 | 44.845
53.746 |  | G53.746x2.309 | G 1 3/4 | 11 | A | 53.746 | 53.386 | 52.267 | 52.087 | 50.788 |  |  | 50.788 | 51.428 | 52.267 | 52.447 | 53.746 |  | 44.4500 | 107.492 | 10.5000
53.746 |  | G53.746x2.309 | G 1 3/4 | 11 | B | 53.746 | 53.386 | 52.267 | 51.907 | 50.788
59.614 |  | G59.614x2.309 | G 2 | 11 | A | 59.614 | 59.254 | 58.135 | 57.955 | 56.656 |  |  | 56.656 | 57.296 | 58.135 | 58.315 | 59.614 |  | 50.8000 | 119.228 | 10.5000
59.614 |  | G59.614x2.309 | G 2 | 11 | B | 59.614 | 59.254 | 58.135 | 57.775 | 56.656
65.710 |  | G65.71x2.309 | G 2 1/4 | 11 | A | 65.710 | 65.276 | 64.231 | 64.014 | 62.752 |  |  | 62.752 | 63.392 | 64.231 | 64.448 | 65.710 |  | 57.1500 | 131.420 | 10.5000
65.710 |  | G65.71x2.309 | G 2 1/4 | 11 | B | 65.710 | 65.276 | 64.231 | 63.797 | 62.752
75.184 |  | G75.184x2.309 | G 2 1/2 | 11 | A | 75.184 | 74.750 | 73.705 | 73.488 | 72.226 |  |  | 72.226 | 72.866 | 73.705 | 73.922 | 75.184 |  |  | 150.368 | 10.5000
75.184 |  | G75.184x2.309 | G 2 1/2 | 11 | B | 75.184 | 74.750 | 73.705 | 73.271 | 72.226
81.534 |  | G81.534x2.309 | G 2 3/4 | 11 | A | 81.534 | 81.100 | 80.055 | 79.838 | 78.576 |  |  | 78.576 | 79.216 | 80.055 | 80.272 | 81.534 |  | 69.8500 | 163.068 | 10.5000
81.534 |  | G81.534x2.309 | G 2 3/4 | 11 | B | 81.534 | 81.100 | 80.055 | 79.621 | 78.576
87.884 |  | G87.884x2.309 | G 3 | 11 | A | 87.884 | 87.450 | 86.405 | 86.188 | 84.926 |  |  | 84.926 | 85.566 | 86.405 | 86.622 | 87.884 |  | 76.2000 | 175.768 | 10.5000
87.884 |  | G87.884x2.309 | G 3 | 11 | B | 87.884 | 87.450 | 86.405 | 85.971 | 84.926
100.330 |  | G100.33x2.309 | G 3 1/2 | 11 | A | 100.330 | 99.896 | 98.851 | 98.634 | 97.372 |  |  | 97.372 | 98.012 | 98.851 | 99.068 | 100.330 |  | 88.9000 | 200.660 | 10.5000
100.330 |  | G100.33x2.309 | G 3 1/2 | 11 | B | 100.330 | 99.896 | 98.851 | 98.417 | 97.372
113.030 |  | G113.03x2.309 | G 4 | 11 | A | 113.030 | 112.596 | 111.551 | 111.334 | 110.072 |  |  | 110.072 | 110.712 | 111.551 | 111.768 | 113.030 |  | 101.6000 | 226.060 | 10.5000
113.030 |  | G113.03x2.309 | G 4 | 11 | B | 113.030 | 112.596 | 111.551 | 111.117 | 110.072
125.730 |  | G125.73x2.309 | G 4 1/2 | 11 | A | 125.730 | 125.296 | 124.251 | 124.034 | 122.772 |  |  | 122.772 | 123.412 | 124.251 | 124.468 | 125.730 |  | 114.3000 | 251.460 | 10.5000
125.730 |  | G125.73x2.309 | G 4 1/2 | 11 | B | 125.730 | 125.296 | 124.251 | 123.817 | 122.772
138.430 |  | G138.43x2.309 | G 5 | 11 | A | 138.430 | 137.996 | 136.951 | 136.734 | 135.472 |  |  | 135.472 | 136.112 | 136.951 | 137.168 | 138.430 |  | 127.0000 | 276.860 | 10.5000
138.430 |  | G138.43x2.309 | G 5 | 11 | B | 138.430 | 137.996 | 136.951 | 136.517 | 135.472
151.130 |  | G151.13x2.309 | G 5 1/2 | 11 | A | 151.130 | 150.696 | 149.651 | 149.434 | 148.172 |  |  | 148.172 | 148.812 | 149.651 | 149.868 | 151.130 |  | 139.7000 | 302.260 | 10.5000
151.130 |  | G151.13x2.309 | G 5 1/2 | 11 | B | 151.130 | 150.696 | 149.651 | 149.217 | 148.172
163.830 |  | G163.83x2.309 | G 6 | 11 | A | 163.830 | 163.396 | 162.351 | 162.134 | 160.872 |  |  | 160.872 | 161.512 | 162.351 | 162.568 | 163.830 |  | 152.4000 | 327.660 | 10.5000
163.830 |  | G163.83x2.309 | G 6 | 11 | B | 163.830 | 163.396 | 162.351 | 161.917 | 160.872

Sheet: BSP Pipe Threads
M Q | BSP Pipe Threads |  | Sort Order - 19 |  | External |  |  |  |  |  |  | Internal
 |  |  |  |  |  | Major Dia |  | Pitch Dia |  | Minor Dia |  |  | Minor Dia |  | Pitch Dia |  | Major Dia |  | Tap Drill | Thread Depth | Thread Runouts
Size | Size Suffix | Thread Designation | Custom Thread Designation | TPI | Class | Max | Min | Max | Min | Max | Min | Class | Min | Max | Min | Max | Min | Max | Basic |  | Basic
1/16 |  | G 1/16-28 | G 1/16-28 | 28 | A | 7.723 | 7.509 | 7.142 | 7.035 | 6.561 |  |  | 6.561 | 6.834 | 7.142 | 7.249 | 7.723 |  | 6.6000 | 15.4460 | 4.5000
1/16 |  | G 1/16-28 | G 1/16-28 | 28 | B | 7.723 | 7.509 | 7.142 | 7.035 | 6.561
1/8 |  | G 1/8-28 | G 1/8-28 | 28 | A | 9.728 | 9.514 | 9.147 | 9.040 | 8.566 |  |  | 8.566 | 8.848 | 9.147 | 9.254 | 9.728 |  | 8.7300 | 19.4560 | 4.5000
1/8 |  | G 1/8-28 | G 1/8-28 | 28 | B | 9.728 | 9.514 | 9.147 | 9.040 | 8.566
1/4 |  | G 1/4-19 | G 1/4-19 | 19 | A | 13.157 | 12.907 | 12.301 | 12.176 | 11.445 |  |  | 11.445 | 11.89 | 12.301 | 12.426 | 13.157 |  | 11.8000 | 26.3140 | 6.5000
1/4 |  | G 1/4-19 | G 1/4-19 | 19 | B | 13.157 | 12.907 | 12.301 | 12.176 | 11.445
3/8 |  | G 3/8-19 | G 3/8-19 | 19 | A | 16.662 | 16.412 | 15.806 | 15.681 | 14.950 |  |  | 14.95 | 15.395 | 15.806 | 15.931 | 16.662 |  | 15.2500 | 33.3240 | 6.5000
3/8 |  | G 3/8-19 | G 3/8-19 | 19 | B | 16.662 | 16.412 | 15.806 | 15.681 | 14.950
1/2 |  | G 1/2-14 | G 1/2-14 | 14 | A | 20.955 | 20.671 | 19.793 | 19.651 | 18.631 |  |  | 18.631 | 19.172 | 19.793 | 19.935 | 20.955 |  | 19.0500 | 41.9100 | 8.5000
1/2 |  | G 1/2-14 | G 1/2-14 | 14 | B | 20.955 | 20.671 | 19.793 | 19.651 | 18.631
5/8 |  | G 5/8-14 | G 5/8-14 | 14 | A | 22.911 | 22.627 | 21.749 | 21.607 | 20.587 |  |  | 20.587 | 21.128 | 21.749 | 21.891 | 22.911 |  | 21.0000 | 45.8220 | 8.5000
5/8 |  | G 5/8-14 | G 5/8-14 | 14 | B | 22.911 | 22.627 | 21.749 | 21.607 | 20.587
3/4 |  | G 3/4-14 | G 3/4-14 | 14 | A | 26.441 | 26.157 | 25.279 | 25.137 | 24.117 |  |  | 24.117 | 24.658 | 25.279 | 25.421 | 26.441 |  | 24.5000 | 52.8820 | 8.5000
3/4 |  | G 3/4-14 | G 3/4-14 | 14 | B | 26.441 | 26.157 | 25.279 | 25.137 | 24.117
7/8 |  | G 7/8-14 | G 7/8-14 | 14 | A | 30.201 | 29.917 | 29.039 | 28.897 | 27.877 |  |  | 27.877 | 28.418 | 29.039 | 29.181 | 30.201 |  | 28.2500 | 60.4020 | 8.5000
7/8 |  | G 7/8-14 | G 7/8-14 | 14 | B | 30.201 | 29.917 | 29.039 | 28.897 | 27.877
1 |  | G 1-11 | G 1-11 | 11 | A | 33.249 | 32.889 | 31.770 | 31.590 | 30.291 |  |  | 30.291 | 30.931 | 31.77 | 31.95 | 33.249 |  | 30.7500 | 66.4980 | 10.0000
1 |  | G 1-11 | G 1-11 | 11 | B | 33.249 | 32.889 | 31.770 | 31.590 | 30.291
1 1/4 |  | G 1 1/4-11 | G 1 1/4-11 | 11 | A | 41.910 | 41.550 | 40.431 | 40.251 | 38.952 |  |  | 38.952 | 39.592 | 40.431 | 40.611 | 41.910 |  | 39.5000 | 83.8200 | 10.0000
1 1/4 |  | G 1 1/4-11 | G 1 1/4-11 | 11 | B | 41.910 | 41.550 | 40.431 | 40.251 | 38.952
1 1/2 |  | G 1 1/2-11 | G 1 1/2-11 | 11 | A | 47.803 | 47.443 | 46.324 | 46.144 | 44.845 |  |  | 44.845 | 45.485 | 46.324 | 46.504 | 47.803 |  | 45.5000 | 95.6060 | 10.0000
1 1/2 |  | G 1 1/2-11 | G 1 1/2-11 | 11 | B | 47.803 | 47.443 | 46.324 | 46.144 | 44.845
1 3/4 |  | G 1 3/4-11 | G 1 3/4-11 | 11 | A | 53.746 | 53.386 | 52.267 | 52.087 | 50.788 |  |  | 50.788 | 51.428 | 52.267 | 52.447 | 53.746 |  | 51.0000 | 107.4920 | 10.0000
1 3/4 |  | G 1 3/4-11 | G 1 3/4-11 | 11 | B | 53.746 | 53.386 | 52.267 | 52.087 | 50.788
2 |  | G 2-11 | G 2-11 | 11 | A | 59.614 | 59.254 | 58.135 | 57.955 | 56.656 |  |  | 56.656 | 57.296 | 58.135 | 58.315 | 59.614 |  | 57.0000 | 119.2280 | 10.0000
2 |  | G 2-11 | G 2-11 | 11 | B | 59.614 | 59.254 | 58.135 | 57.955 | 56.656
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

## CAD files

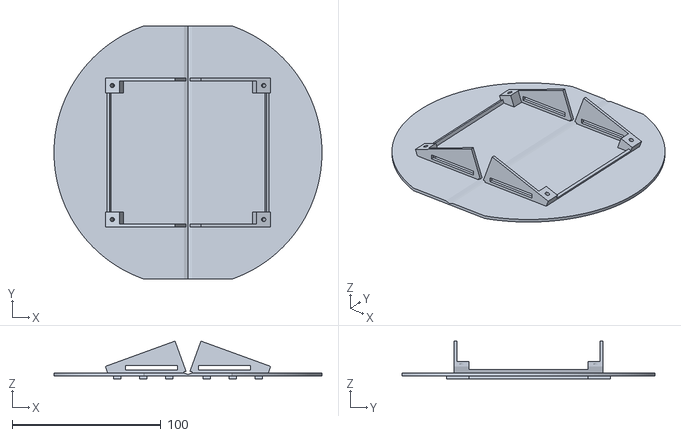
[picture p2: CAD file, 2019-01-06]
3D_files/larger_overhang_roof.stl
180.0 x 170.0 x 25.4

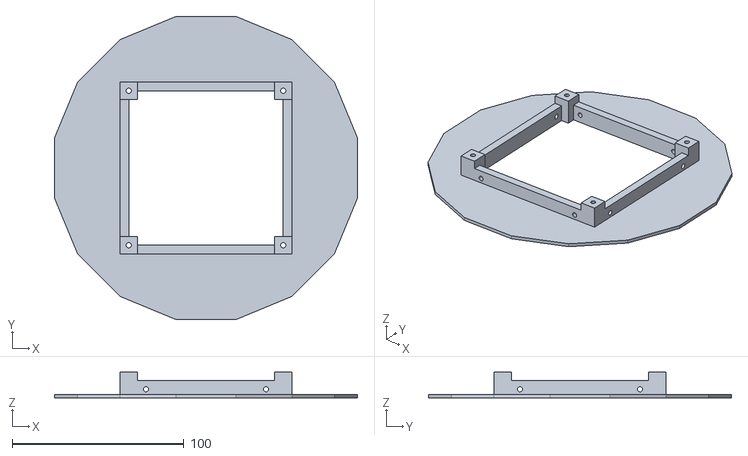
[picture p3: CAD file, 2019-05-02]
Weather_Station_Project/composite_base.stl
176.5 x 176.5 x 15.0

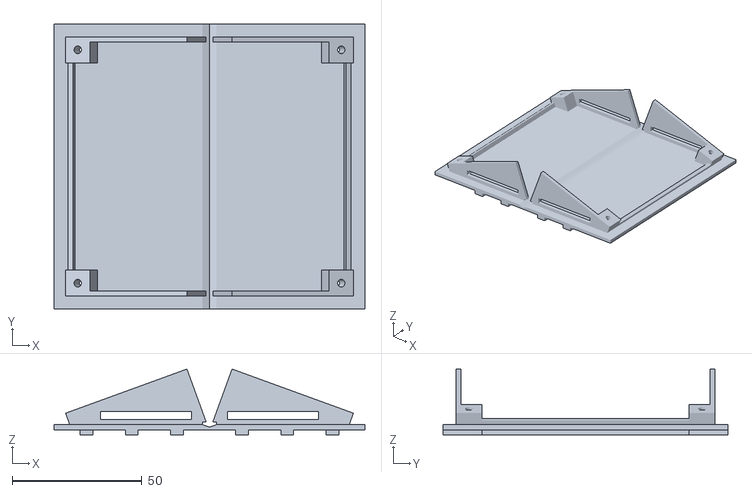
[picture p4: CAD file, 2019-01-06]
3D_files/new_roof.stl
120.0 x 110.0 x 25.4

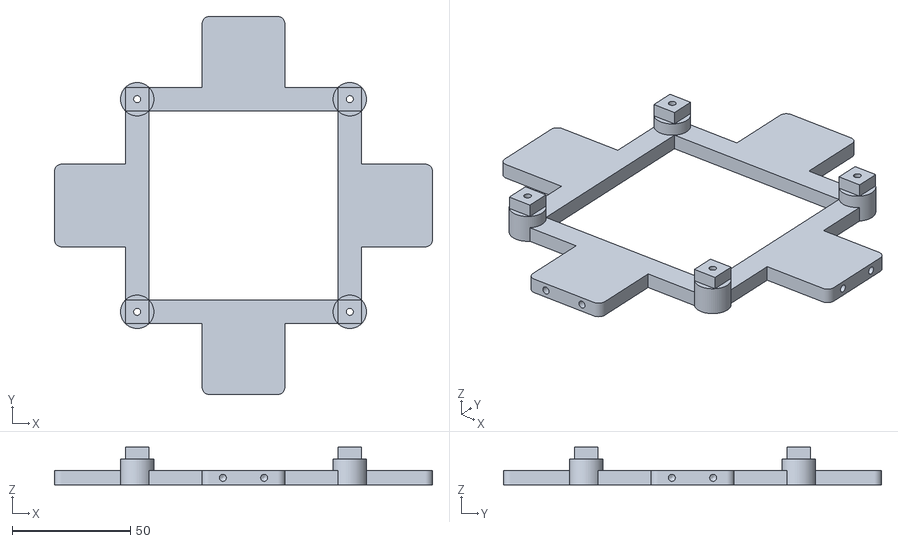
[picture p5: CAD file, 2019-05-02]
Weather_Station_Project/solar roof.stl
160.0 x 160.0 x 16.0

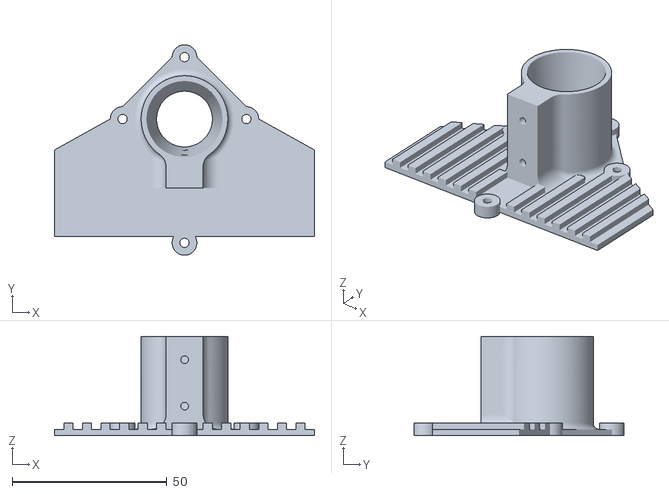
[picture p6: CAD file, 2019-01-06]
3D_files/cover_clip.stl
84.0 x 68.0 x 32.0

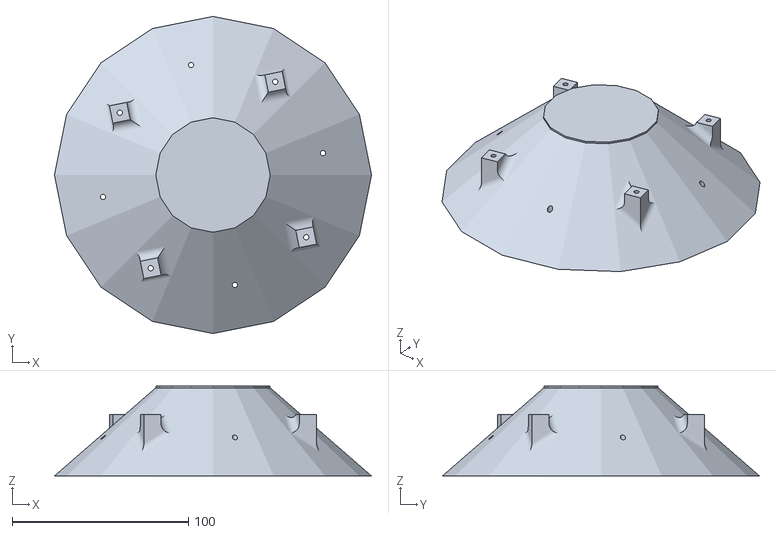
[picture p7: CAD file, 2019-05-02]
Weather_Station_Project/cone_pattern_top.stl
180.0 x 180.0 x 51.0

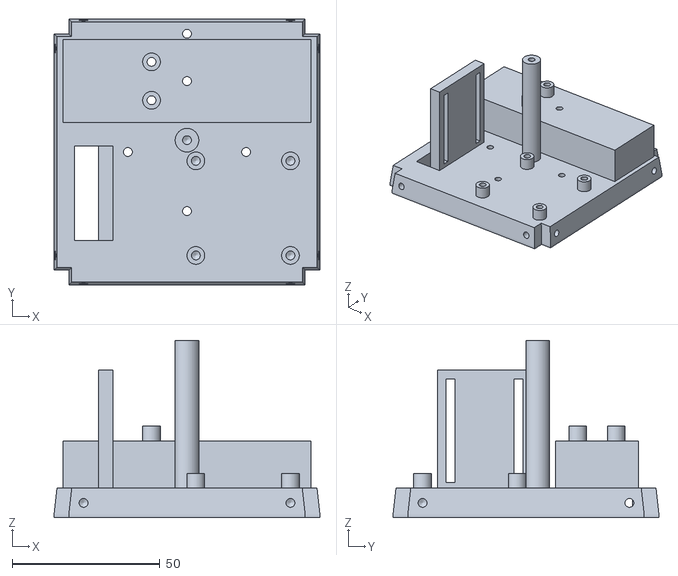
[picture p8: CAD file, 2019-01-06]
3D_files/boxbase_solar.stl
90.0 x 90.0 x 60.0

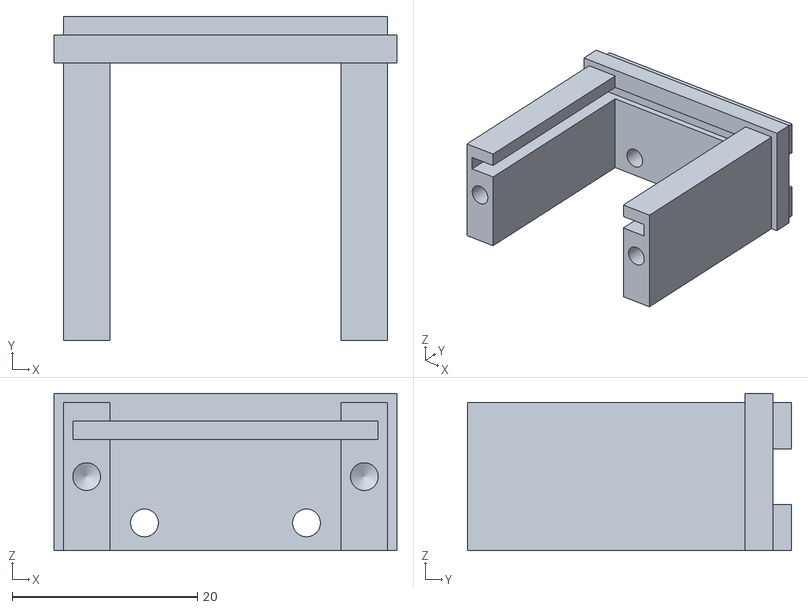
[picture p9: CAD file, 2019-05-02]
Weather_Station_Project/uv_sensor_housing.stl
37.0 x 35.0 x 17.0

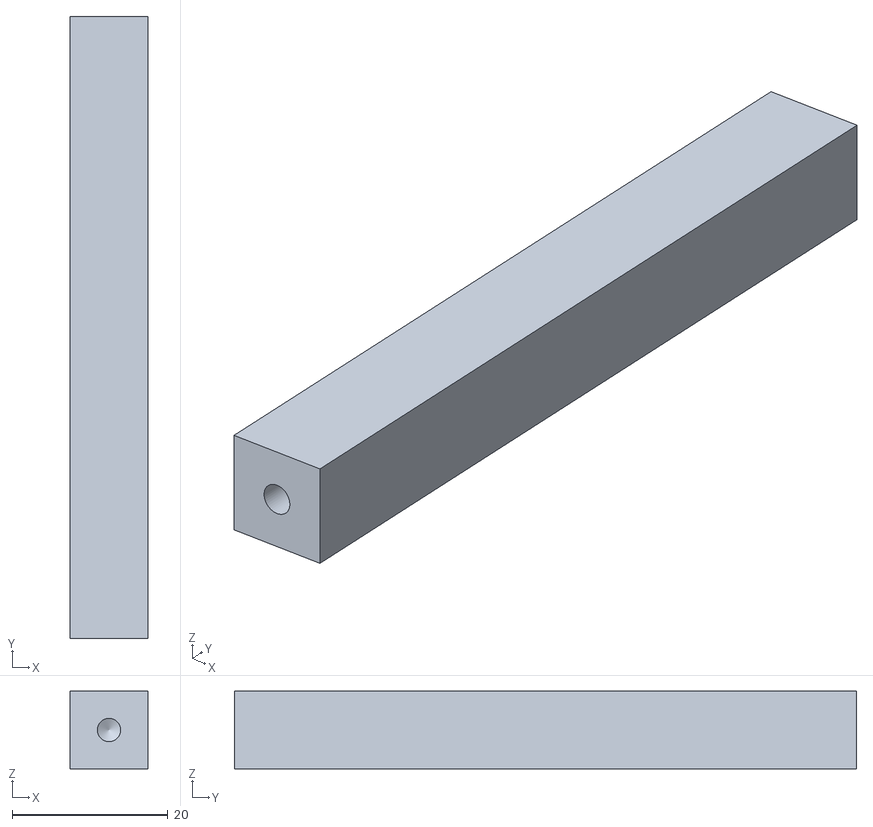
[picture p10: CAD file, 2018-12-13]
3D_files/rod.stl
10.0 x 80.0 x 10.0

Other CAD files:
Weather_Station_Project/Templates/English/ANSI (in).dwg
Weather_Station_Project/Templates/Metric/ISO.dwg
Weather_Station_Project/Templates/Standard.dwg
Weather_Station_Project/Templates/English/am_ansi.dwg
Weather_Station_Project/Templates/Metric/am_bsi.dwg
Weather_Station_Project/Templates/Metric/JIS.dwg
Weather_Station_Project/Templates/Metric/DIN.dwg
Weather_Station_Project/cover_clip.stl
Weather_Station_Project/Templates/Metric/am_din.dwg
3D_files/base.stl
3D_files/insert.stl
3D_files/roof_foldable.stl
3D_files/truss.stl
Weather_Station_Project/Design Data/AIT/Mold Design/mold design stop pin.ipt
Weather_Station_Project/Design Data/Cable & Harness/en-US/harness.iam
Weather_Station_Project/Design Data/Tube & Pipe/en-US/piping runs.iam
Weather_Station_Project/Templates/English/ANSI (in).idw
Weather_Station_Project/Templates/English/Mold Design (in).iam
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

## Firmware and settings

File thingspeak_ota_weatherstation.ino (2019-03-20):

/*
   ESP8266 Weather Station by Wilyarti Howard (C) 2019
   github.com/wilyarti
   License BSD 2
*/
#include <EEPROM.h>
#include <BME280I2C.h>
#include <ESP8266WiFi.h>
#include <ThingSpeak.h>
#include <time.h>
#include <Wire.h>
#include "Adafruit_SHT31.h"
#include "rain_functions.h"
#include "config.h"

// ota includes
#include <ESP8266WiFi.h>
#include <ESP8266HTTPClient.h>
#include <ESP8266httpUpdate.h>
#include <DNSServer.h>
#include <ESP8266WebServer.h>
#include <WiFiManager.h>
#include <ArduinoJson.h>
#include <EEPROM.h>
#include <Ticker.h>
// ----

// ota updater stuff
const String VERSION = "15";

#define LED_PIN 2 // gpio2 for ESP-12, gpio1 for ESP-01

#define METADATA_CHK_SECS 24 * 60 * 60 // Check for updated config metadata once a day

// this is the config persisted to EEPROM so retained over power offs
typedef struct {
    String thingSpeakChannel;
    String thingSpeakKey;
    int    publishInterval;
    int    initializedFlag;
} _Config;

_Config theConfig;

// this counts the deep sleep wakeups to time when a day is up
typedef struct {
    int wakeupCounter;
    int initializedFlag;
} _rtcStore;

_rtcStore rtcStore;

#define INITIALIZED_MARKER 7216
Ticker ledBlinker;
//


// configure options - rain/sensors etc
#define RAIN_OPT  true
//#define DEEP_SLEEP_OPT true
#define UV_OPT true
//#define DHT_OPT true
#define BMP_OPT true

#ifdef UV_OPT
#include <VEML6075.h>
VEML6075 uv = VEML6075();
#endif

#ifdef DHT_OPT
#include <DHT.h>
#include <DHT_U.h>
#define DHTPIN 2
#define DHTTYPE    DHT22     
DHT_Unified dht(DHTPIN, DHTTYPE);
#endif
// global variables
int sleepTime = 60;
int measureCount = 0;
unsigned long curTime;
bool justWokeUp = true;

// initialise functions
WiFiClient client;
BME280I2C bme;
Adafruit_SHT31 sht31 = Adafruit_SHT31();

void setup() {
    #ifdef RAIN_OPT
    // initialize rain
    initializeRainGauge();
    #endif

    Serial.println("Loading config...");
    loadConfig();
    #ifdef DEEP_SLEEP_OPT
    Serial.println("Checking wake up count...");
    doWakeupCount();
    if (rtcStore.wakeupCounter == 0) {
        updateConfigFromChannelMetadata();
    }
    #endif
    Serial.println("Connecting to Wifi...");
    if (WiFi.waitForConnectResult() != WL_CONNECTED) {
        // fast blink LED while Wifi manager running config AP
        ledBlinker.attach(0.2, []() {
            digitalWrite(LED_PIN, !digitalRead(LED_PIN));
        });
        doWifiManager();
        ledBlinker.detach();
        digitalWrite(LED_PIN, HIGH); // off
    }

    Serial.begin(115200);
    Serial.println();
    Serial.print("Firmware version: ");
    Serial.println(VERSION);
    // setup sensors
    Wire.begin(5,4);

    #ifdef BMP_OPT
    // begin bmp280
    curTime = millis();
    while (!bme.begin()) {
        if (millis() - curTime > (60 * 1000)) {
            break;
        }
        Serial.print("Initializing BMP sensor ");
        Serial.println(millis() - curTime);
        delay(1000);
    }
    #endif
    #ifdef DHT_OPT
    dht.begin();
    #else
    // begin sht31
    curTime = millis();
    while (!sht31.begin(0x44)) {
        Serial.print("Initializing SHT sensor ");
        if (millis() - curTime > (60 * 1000)) {
            break;
        }
        Serial.println(millis() - curTime);
        delay(1000);
    }
    #endif
    // bme.chipID(); // Deprecated. See chipModel().
    switch (bme.chipModel()) {
        case BME280::ChipModel_BME280:
            Serial.println("Found BME280 sensor! Success.");
            break;
        case BME280::ChipModel_BMP280:
            Serial.println("Found BMP280 sensor! No Humidity available.");
            break;
        default:
            Serial.println("Found UNKNOWN sensor! Error!");
    }
    #ifdef UV_OPT
    // uv guage
    while (!uv.begin())
    {
        if (millis() - curTime > (60 * 1000)) {
            break;
        }
        Serial.println("Waiting on UV sensor....");
        Serial.println(millis() - curTime);
        delay(1000);
    }
    #endif
    if(justWokeUp) {
        updateConfigFromChannelMetadata();
        justWokeUp = false;
    }

}

void loop() {
    if (measureCount == 1000) {
        updateConfigFromChannelMetadata();
        measureCount = 0;
    }

    Serial.println("Measuring...");
    measure();

    Serial.println("Going to sleep...");
    goToSleep();
}

void goToSleep() {
    Serial.print("Up for ");
    Serial.print(millis());
    Serial.print(" milliseconds, going to sleep for ");
    Serial.print(theConfig.publishInterval);
    Serial.println(" seconds");

    float volt = 0.0;
    unsigned int raw = 0;
    pinMode(A0, INPUT);
    raw = analogRead(A0);
    volt = raw / 1023.0;
    volt = volt * REF_VOLTAGE;

    if (volt > 4.0) {
        sleepTime = theConfig.publishInterval;
    } else if (volt > 3.9) {
        sleepTime = theConfig.publishInterval * 1.5;
    } else if (volt > 3.85) {
        sleepTime = theConfig.publishInterval * 2;
    } else if (volt > 3.75) {
        sleepTime = theConfig.publishInterval * 3;
    } else {
        sleepTime = theConfig.publishInterval * 6;
    }
    Serial.print("Sleeping for: ");
    Serial.print(sleepTime);
    Serial.println(" seconds.");

#ifdef DEEP_SLEEP_OPT
    Serial.print("Deep sleeping....");
    ESP.deepSleep(sleepTime * 1000000);
#else
    Serial.println("Not sleeping just using a delay....");
    // deepsleep wont work with interrupts ---- sorry
    delay(sleepTime * 1000);
#endif
    //delay(10*1000);
}


void measure() {
    float t(NAN);
    float t1(NAN);
    float p(NAN);
    float h(NAN);
    float h1(NAN);
    float volt = 0.0;
    unsigned int raw = 0;
    #ifdef BMP_OPT
     // bmp/bme
    BME280::TempUnit tempUnit(BME280::TempUnit_Celsius);
    BME280::PresUnit presUnit(BME280::PresUnit_Pa);
    bme.read(p, t, h, tempUnit, presUnit);
    // ----
    #endif
    
    #ifdef DHT_OPT
    sensor_t sensor;
    dht.temperature().getSensor(&sensor);
    sensors_event_t event;
    dht.temperature().getEvent(&event);
    if (isnan(event.temperature)) {
      Serial.println(F("Error reading temperature!"));
    }
    else {
      Serial.print(F("Temperature: "));
      Serial.print(event.temperature);
      Serial.println(F("°C"));
      t1 = event.temperature;
    }
    // Get humidity event and print its value.
    dht.humidity().getEvent(&event);
    if (isnan(event.relative_humidity)) {
      Serial.println(F("Error reading humidity!"));
    }
    else {
      Serial.print(F("Humidity: "));
      Serial.print(event.relative_humidity);
      Serial.println(F("%"));
      h1 = event.relative_humidity;
    }
    #else
    // sht31
     t1 = sht31.readTemperature();
     h1 = sht31.readHumidity();

    if (!isnan(t1)) {  // check if 'is not a number'
        Serial.print("Temp *C = ");
        Serial.println(t1);
    } else {
        Serial.println("Failed to read temperature");
    }

    if (!isnan(h1)) {  // check if 'is not a number'
        Serial.print("Hum. % = ");
        Serial.println(h1);
    } else {
        Serial.println("Failed to read humidity");
    }
    // ----
    #endif

    #ifdef UV_OPT
    /// uv sensor
    uv.poll();
    float uva(NAN);
    float uvb(NAN);
    float uvi(NAN);

    uva = uv.getUVA();
    uvb = uv.getUVB();
    uvi = uv.getUVIndex();

    if (!isnan(uva)) {  // check if 'is not a number'
        Serial.print("UVA: ");
        Serial.println(uva);
    } else {
        Serial.println("Failed to read UV data.");
    }
    if (!isnan(uvb)) {  // check if 'is not a number'
        Serial.print("UVB: ");
        Serial.println(uvb);
    } else {
        Serial.println("Failed to read UV data.");
    }
    if (!isnan(uvi)) {  // check if 'is not a number'
        Serial.print("UV Index: ");
        Serial.println(uvi);
    } else {
        Serial.println("Failed to read UV data.");
    }
    // ----
#endif

    Serial.print("Temperature: ");
    Serial.print(t);
    Serial.println(" Celcius\nPressure: ");
    Serial.print(p);
    Serial.print("Humidity: ");
    Serial.println(h);
    Serial.print("Rain: ");
    Serial.println(getRainMM());
    Serial.println("% send to Thingspeak");

    // 1.005 mOhm and 305 kOhm
    pinMode(A0, INPUT);
    raw = analogRead(A0);
    volt = raw / 1023.0;
    volt = volt * REF_VOLTAGE;
    Serial.print(volt);

    // wifi
    float rssi = WiFi.RSSI();

    String url = String("http://api.thingspeak.com/update?api_key=") + theConfig.thingSpeakKey +
                 "&field1=" + t1 +
                 "&field2=" + p +
                 "&field3=" + h1 +
                 "&field4=" + volt +
                 "&field5=" + rssi
                 + "&field6=" + measureCount
                 #ifdef RAIN_OPT
                 + "&field7=" + getRainMM()
                 #endif
                 #ifdef UV_OPT
                 + "&field8=" + uvi
                 #endif
    ;


    Serial.println(url);
    HTTPClient http;
    http.begin(url);
    int httpCode = http.GET();

    // reset rain if successful
    if (httpCode == 200) {
        rainEventCount = 0;
    }
    Serial.print("sendReading: httpCode: ");
    Serial.println(httpCode);
    http.end();

    measureCount++;

}

// esp ota functions
void doWakeupCount() {
    system_rtc_mem_read(65, &rtcStore, sizeof(rtcStore));

    if (rtcStore.initializedFlag != INITIALIZED_MARKER) {
        rtcStore.initializedFlag = INITIALIZED_MARKER;
        rtcStore.wakeupCounter = 0;
    } else {
        rtcStore.wakeupCounter += 1;
    }

    if (theConfig.publishInterval * rtcStore.wakeupCounter > METADATA_CHK_SECS) {
        rtcStore.wakeupCounter = 0;
    }

    system_rtc_mem_write(65, &rtcStore, sizeof(rtcStore));

    Serial.print("doWakeupCount: rtcStore.initializedFlag="); Serial.print(rtcStore.initializedFlag);
    Serial.print(", rtcStore.wakeupCounter="); Serial.println(rtcStore.wakeupCounter);
}

bool shouldSaveConfig = false;

void doWifiManager() {
    WiFiManagerParameter custom_thingspeak_channel("channel", "ThingSpeak Channel", theConfig.thingSpeakChannel.c_str(), 9);
    WiFiManagerParameter custom_thingspeak_key("key", "ThingSpeak Key", theConfig.thingSpeakKey.c_str(), 17);
    WiFiManagerParameter custom_publish_interval("publishInterval", "Publish Interval", String(theConfig.publishInterval).c_str(), 6);

    WiFiManager wifiManager;

    wifiManager.setSaveConfigCallback([]() {
        Serial.println("Should save config");
        shouldSaveConfig = true;
    });

    wifiManager.addParameter(&custom_thingspeak_channel);
    wifiManager.addParameter(&custom_thingspeak_key);
    wifiManager.addParameter(&custom_publish_interval);

    wifiManager.setTimeout(240); // 4 minutes

    //fetches ssid and pass and tries to connect
    //if it does not connect it starts an access point with the specified name
    //and goes into a blocking loop awaiting configuration
    String apName = String("ESP-") + ESP.getChipId();
    if (!wifiManager.autoConnect(apName.c_str())) {
        Serial.println("failed to connect and hit timeout");
        delay(3000);
        //reset and try again, or maybe put it to deep sleep
        ESP.reset();
        delay(5000);
    }

    //if you get here you have connected to the WiFi
    Serial.println("connected...yeey :)");

    //read updated parameters
    theConfig.thingSpeakChannel = String(custom_thingspeak_channel.getValue());
    theConfig.thingSpeakKey = String(custom_thingspeak_key.getValue());
    theConfig.publishInterval = String(custom_publish_interval.getValue()).toInt();

    //save the custom parameters to FS
    if (shouldSaveConfig) {
        Serial.println("saving config");
        saveConfig();
    }

    Serial.println("local ip");
    Serial.println(WiFi.localIP());
}

void updateConfigFromChannelMetadata() {
    String url = String("http://api.thingspeak.com/channels/") + theConfig.thingSpeakChannel + "/feeds.json?metadata=true&results=0";
    Serial.print("updateConfigFromChannelMetadata: "); Serial.println(url);
    HTTPClient http;
    http.begin(url);
    int httpCode = http.GET();
    Serial.print("updateConfigFromChannelMetadata httpCode: ");  Serial.println(httpCode);
    String payload = http.getString();
    http.end();
    if (payload.length() < 1) {
        return;
    }

    StaticJsonBuffer<1024> jsonBuffer;
    JsonObject& root = jsonBuffer.parseObject(payload);
    if (!root.success()) {
        Serial.print("updateConfigFromChannelMetadata: payload parse FAILED: ");
        Serial.print("payload: "); Serial.println(payload);
        return;
    }
    Serial.print("updateConfigFromChannelMetadata: payload parse OK: "); root.prettyPrintTo(Serial); Serial.println();

    String metaDate = root["channel"]["metadata"];
    Serial.println(metaDate);

    StaticJsonBuffer<500> jsonBuffer2;
    JsonObject& md = jsonBuffer2.parseObject(metaDate);
    if (!md.success()) {
        Serial.print("updateConfigFromChannelMetadata: md parse FAILED: ");
        Serial.print("updateConfigFromChannelMetadata: md: "); Serial.println(metaDate);
        return;
    }
    Serial.print("updateConfigFromChannelMetadata: metaDate parse OK: "); md.prettyPrintTo(Serial); Serial.println();

    boolean configUpdated = false;
    if (md.containsKey("publishInterval")) {
        int pi = md["publishInterval"];
        if (pi != theConfig.publishInterval) {
            theConfig.publishInterval = pi;
            configUpdated = true;
        }
    } else {
        Serial.println("updateConfigFromChannelMetadata: no publish interval");
    }

    if (configUpdated) {
        saveConfig();
    }

    if (md.containsKey("firmwareURL")) {
        if (md.containsKey("firmwareVersion")) {
            String firmwareV = md["firmwareVersion"];
            String firmwareUrl = md["firmwareURL"];
            if (firmwareV != VERSION) {
                doFirmwareUpdate(firmwareUrl);
            }
        } else {
            Serial.println("updateConfigFromChannelMetadata: no firmwareVersion");
        }
    } else {
        Serial.println("updateConfigFromChannelMetadata: no firmwareURL");
    }
}

void saveConfig() {
    EEPROM.begin(512);
    int addr = 0;
    EEPROM.put(addr, INITIALIZED_MARKER);
    addr += sizeof(INITIALIZED_MARKER);
    addr = eepromWriteString(addr, theConfig.thingSpeakChannel);
    addr = eepromWriteString(addr, theConfig.thingSpeakKey);
    EEPROM.put(addr, theConfig.publishInterval);
    addr += sizeof(theConfig.publishInterval);

    // update loadConfig() and printConfig() if anything else added here

    EEPROM.commit();

    Serial.println("Config saved:"); printConfig();
}

void loadConfig() {
    EEPROM.begin(512);

    int addr = 0;
    EEPROM.get(addr, theConfig.initializedFlag);            addr += sizeof(theConfig.publishInterval);
    if (theConfig.initializedFlag != INITIALIZED_MARKER) {
        Serial.println("*** No config!");
        return;
    }

    theConfig.thingSpeakChannel = eepromReadString(addr);   addr += theConfig.thingSpeakChannel.length() + 1;
    theConfig.thingSpeakKey = eepromReadString(addr);       addr += theConfig.thingSpeakKey.length() + 1;
    EEPROM.get(addr, theConfig.publishInterval);            addr += sizeof(theConfig.publishInterval);

    EEPROM.commit();

    Serial.println("Config loaded: "); printConfig();
}

void printConfig() {
    Serial.print("ThingSpeak channel: '"); Serial.print(theConfig.thingSpeakChannel);
    Serial.print("', ThingSpeak Key="); Serial.print(theConfig.thingSpeakKey);
    Serial.print(", publishInterval="); Serial.print(theConfig.publishInterval);
    Serial.println();
}

// get these eeprom read/write String functions in Arduino code somewhere?
int eepromWriteString(int addr, String s) {
    int l = s.length();
    for (int i = 0; i < l; i++) {
        EEPROM.write(addr++, s.charAt(i));
    }
    EEPROM.write(addr++, 0x00);
    return addr;
}

String eepromReadString(int addr) {
    String s;
    char c;
    while ((c = EEPROM.read(addr++)) != 0x00) {
        s += c;
    }
    return s;
}

void doFirmwareUpdate(String firmwareUrl) {
    Serial.print("doFirmwareUpdate: from "); Serial.println(firmwareUrl);

    t_httpUpdate_return ret = ESPhttpUpdate.update(firmwareUrl);
    switch (ret) {
        case HTTP_UPDATE_FAILED:
            Serial.print("doFirmwareUpdate: HTTP_UPDATE_FAILD Error :"); Serial.print(ESPhttpUpdate.getLastError()); Serial.println(ESPhttpUpdate.getLastErrorString());
            break;

        case HTTP_UPDATE_NO_UPDATES:
            Serial.println("doFirmwareUpdate: HTTP_UPDATE_NO_UPDATES");
            break;

        case HTTP_UPDATE_OK:
            Serial.println("doFirmwareUpdate: HTTP_UPDATE_OK");
            break;
    }
}

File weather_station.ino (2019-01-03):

#include <Wire.h>
#include <BME280I2C.h>
#include <ESP8266WiFi.h>
#include <ThingSpeak.h>
#include <time.h>


unsigned long myChannelNumber = 1234;
const char * myWriteAPIKey = "";
const char* ssid = "";
const char* password = "";


const char* server = "api.thingspeak.com";
WiFiClient client;

BME280I2C bme;

int sleepTime = 60;
unsigned long curTime;

void setup() {
   curTime = millis();
  Serial.begin(115200);

  WiFi.begin(ssid, password);

  Serial.println();
  Serial.println();
  Serial.print("Connecting to ");
  Serial.println(ssid);

  WiFi.begin(ssid, password);

  while (WiFi.status() != WL_CONNECTED) {
    if (millis() - curTime > (60 * 1000)) {
      goToSleep();
    }
    Serial.println(millis() - curTime);
    delay(1000);
  }
  Serial.println("");
  Serial.println("WiFi connected");

  Wire.begin();
  while (!bme.begin())
  {
    if (millis() - curTime > (60 * 1000)) {
      goToSleep();
    }
    Serial.println(millis() - curTime);
    delay(1000);
  }
  // bme.chipID(); // Deprecated. See chipModel().
  switch (bme.chipModel())
  {
    case BME280::ChipModel_BME280:
      Serial.println("Found BME280 sensor! Success.");
      break;
    case BME280::ChipModel_BMP280:
      Serial.println("Found BMP280 sensor! No Humidity available.");
      break;
    default:
      Serial.println("Found UNKNOWN sensor! Error!");
  }
  ThingSpeak.begin(client);
  measure();

  // sleep
  WiFi.disconnect(true);
  goToSleep();
}
void goToSleep() {
    Serial.print("Sleeping for: ");
    Serial.print(sleepTime);
    Serial.println(" seconds.");
    ESP.deepSleep(sleepTime * 1000000);
}
void measure() {
  float t(NAN);
  float p(NAN);
  float h(NAN);
  float volt = 0.0;
  unsigned int raw = 0;
  BME280::TempUnit tempUnit(BME280::TempUnit_Celsius);
  BME280::PresUnit presUnit(BME280::PresUnit_Pa);

  bme.read(p, t, h, tempUnit, presUnit);


  Serial.print("Temperature: ");
  Serial.print(t);
  Serial.print(" degrees Celcius Pressure: ");
  Serial.print(p);
  Serial.print(" Humidity: ");
  Serial.print(h);
  Serial.println("% send to Thingspeak");
  pinMode(A0, INPUT);
  raw = analogRead(A0);
  volt = raw / 1023.0;
  volt = volt * 4.2;
  Serial.print(volt);

 if (volt > 4.0) {
  sleepTime = 60;
 } else if (volt > 3.9) {
  sleepTime = 120;
 } else if (volt > 3.85) {
  sleepTime = 180;
 } else if (volt > 3.75) {
  sleepTime = 240;
 } else {
  sleepTime = 60 * 30;
 }

  // wifi
  float rssi = WiFi.RSSI();
  
  ThingSpeak.setField(1, t);
  ThingSpeak.setField(2, p);
  ThingSpeak.setField(3, h);
  ThingSpeak.setField(4, volt);
  ThingSpeak.setField(5, rssi);

  ThingSpeak.writeFields(myChannelNumber, myWriteAPIKey);
}

void loop() {
}

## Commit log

2019-01-03 fix battery consumption issues with wifi down
    [weather_station.ino]
2019-01-20 alter battery throttling to optimize performance
2019-05-02 Add 3D files
    [ANSI (in).dwg, ANSI (in).idw, ANSI (mm).dwg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]
